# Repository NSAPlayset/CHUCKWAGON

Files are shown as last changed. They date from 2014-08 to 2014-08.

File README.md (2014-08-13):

#CHUCKWAGON Firmware

This is the demo code used during our [DEF CON 22 talk](https://www.defcon.org/html/defcon-22/dc-22-speakers.html#Datko). The full slides are [here](https://cryptotronix.files.wordpress.com/2014/08/dc_22_diy_hardware_implant.pdf).

The Arduino sketch can be uploaded to the ATmega32p on the [CryptoCape](https://www.sparkfun.com/products/12773) and the bash scripts are used by the target and host.

## Hardware Files

In the Hardware folder, you'll find the schematic, EAGLE CAD files, and BOM for the CHUCKWAGON. You can get the board directly from [OSH Park](https://oshpark.com/shared_projects/FfikIrhc).

### Connecting the CHUCKWAGON

Attach the male VGA adapter to your target. The LED will indicate if power is being supplied from your target. If so, then you can probably receive up to 1A for your implant. If you are using a 5V Logic system, use the SDA and SCL pins directly. If you are using a 3.3V system, use the 3.3V versions. If you do this, you must supply 3.3V to the 3.3V pin.

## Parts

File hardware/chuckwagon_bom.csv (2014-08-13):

Digi-Key Part Number | Manufacturer | Manufacturer Part Number | Customer Reference | Quantity 1 | Quantity 2 | Quantity 3 | Mfg Std Lead Time | Description | Comments | RoHS Status | Lead Free Status | REACH Status
609-4022-ND | FCI | 10090926-P154XLF |  | 1 | 0 | 0 | 12 Weeks | DSUB HD MALE R/A 15POS SOLDR T/H |  | RoHS Compliant | Lead free | Unaffected Jun-2011
BSS138CT-ND | FAIRCHILD SEMICONDUCTOR (VA) | BSS138 |  | 2 | 0 | 0 | 7 Weeks | MOSFET N-CH 50V 220MA SOT-23 | Alternate Packaging Exists | RoHS Compliant | Lead free | Unaffected Jun-2011
SI2323DDS-T1-GE3CT-ND | VISHAY SILICONIX (VA) | SI2323DDS-T1-GE3 |  | 1 | 0 | 0 | 14 Weeks | MOSFET P-CH 20V 5.3A SOT-23 | Alternate Packaging Exists | RoHS Compliant | Lead free | Not Available
541-1784-1-ND | VISHAY DALE (VA) | RCG060310K0FKEA |  | 4 | 0 | 0 | 10 Weeks | RES 10K OHM 1/10W 1% 0603 SMD | Alternate Packaging Exists | RoHS Compliant | Lead free | Not Available
541-1799-1-ND | VISHAY DALE (VA) | RCG06031K00JNEA |  | 1 | 0 | 0 | 10 Weeks | RES 1K OHM 1/10W 5% 0603 SMD | Alternate Packaging Exists | RoHS Compliant | Lead free | Not Available
160-1436-1-ND | LITE-ON INC (VA) | LTST-C190KRKT |  | 1 | 0 | 0 | 8-10 Weeks | LED SUPER RED CLEAR 0603 SMD | Alternate Packaging Exists | RoHS Compliant | Lead free | Not Available

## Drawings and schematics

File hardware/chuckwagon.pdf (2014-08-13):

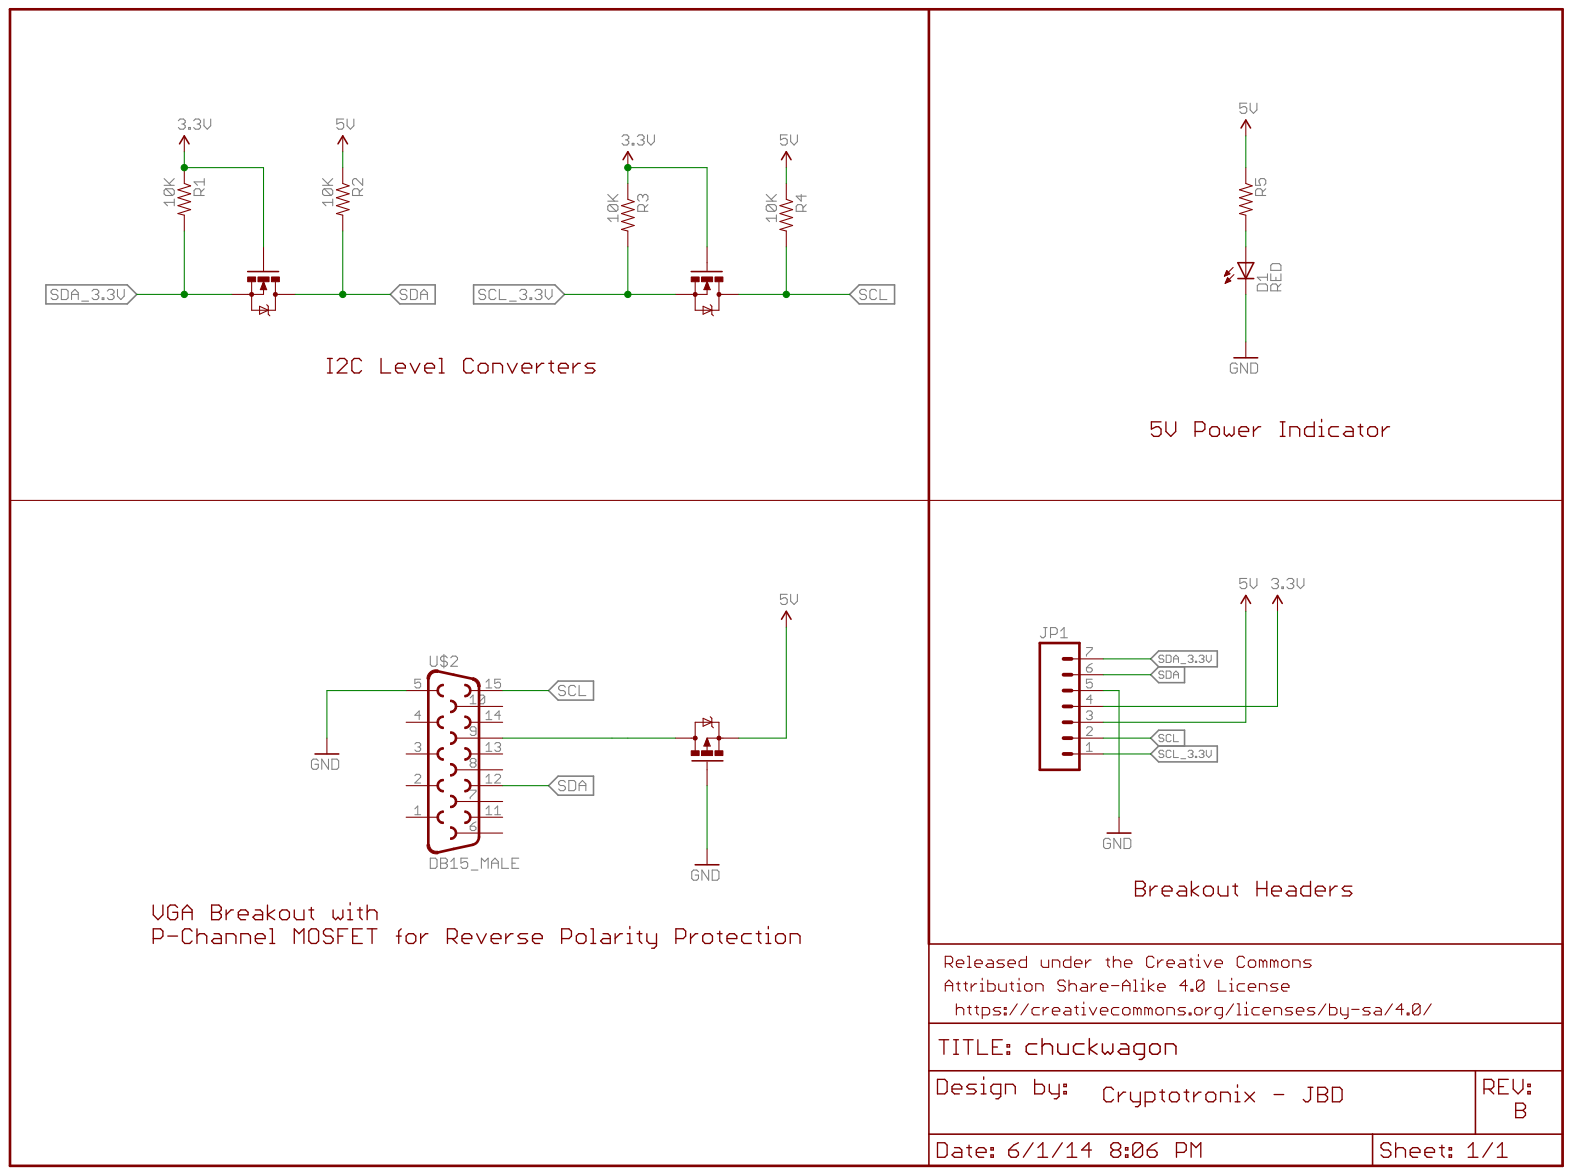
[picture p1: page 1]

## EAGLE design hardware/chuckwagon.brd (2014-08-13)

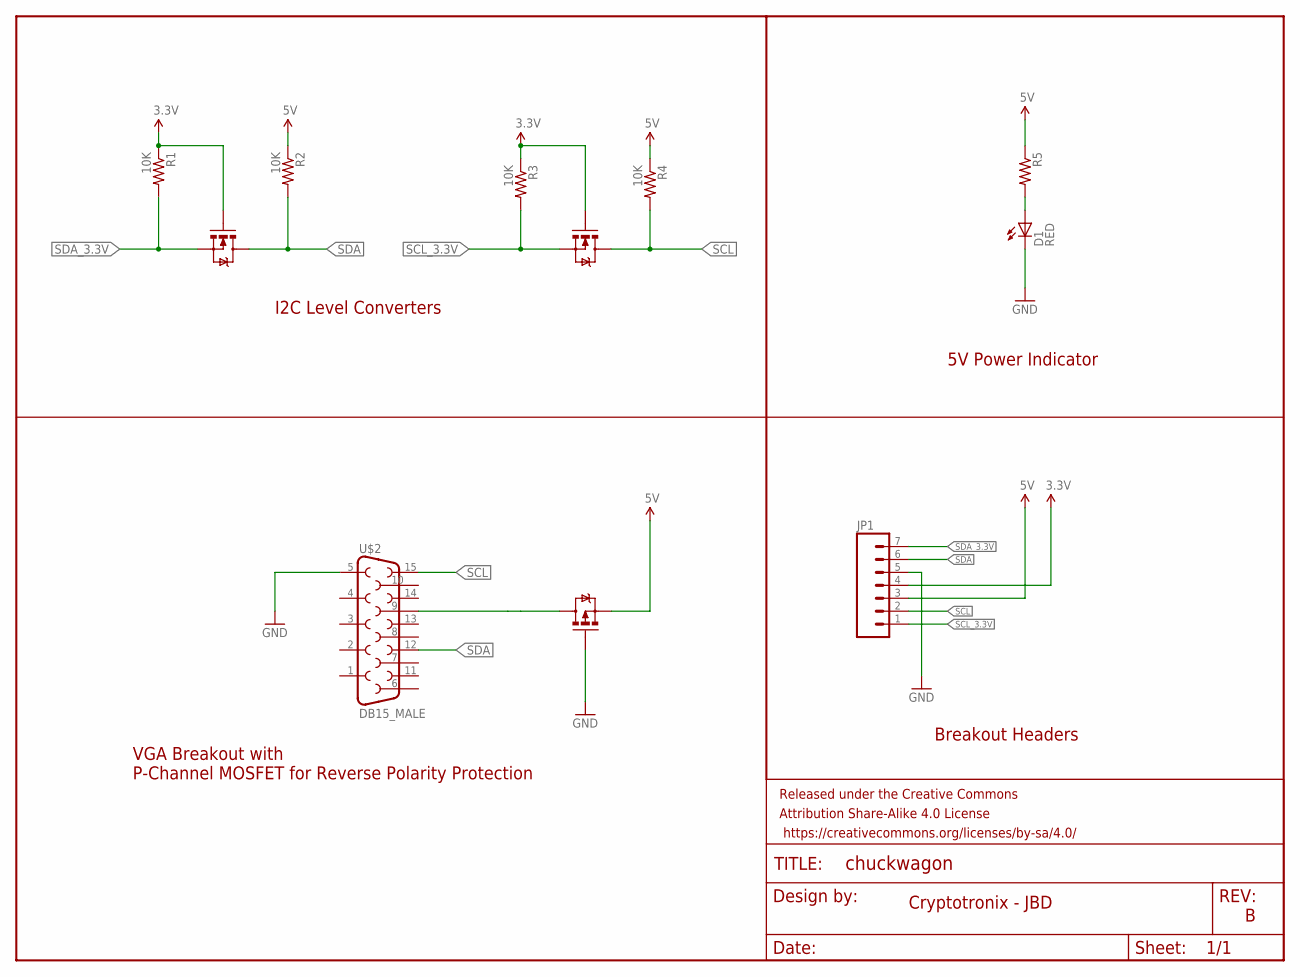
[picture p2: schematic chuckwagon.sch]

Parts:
D1: RED; LED-0603
FRAME1: FRAME-LETTER; CREATIVE_COMMONS
JP1: M07; 1X07
Q1, Q2: MOSFET-NCHANNELBSS123LT1G; SOT23
Q3: MOSFET-PCHANNEL; SOT23-3
R1, R2, R3, R4: 10K; 0603-RES
R5: RESISTOR0603-RES; 0603-RES
U$2: DB15_MALE

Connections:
3.3V: JP1.4, Q1.1 (G), Q2.1 (G), R1.1, R3.1
5V: JP1.3, Q3.2 (S), R2.1, R4.1, R5.1
GND: D1.C, JP1.5, Q3.1 (G), U$2.5
unnamed: D1.A, R5.2
unnamed: Q3.3 (D), U$2.9
SCL: JP1.2, Q2.3 (D), R4.2, U$2.15
SCL_3.3V: JP1.1, Q2.2 (S), R3.2
SDA: JP1.6, Q1.3 (D), R2.2, U$2.12
SDA_3.3V: JP1.7, Q1.2 (S), R1.2

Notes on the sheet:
I2C Level Converters
Breakout Headers
VGA Breakout with P-Channel MOSFET for Reverse Polarity Protection
5V Power Indicator
Cryptotronix - JBD

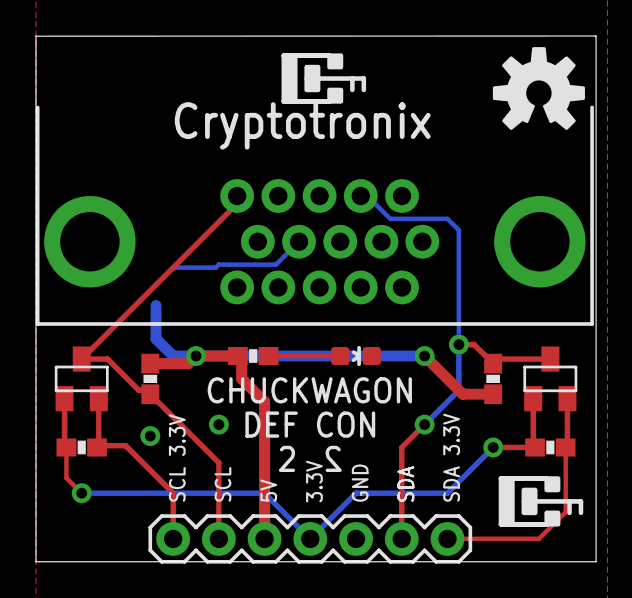
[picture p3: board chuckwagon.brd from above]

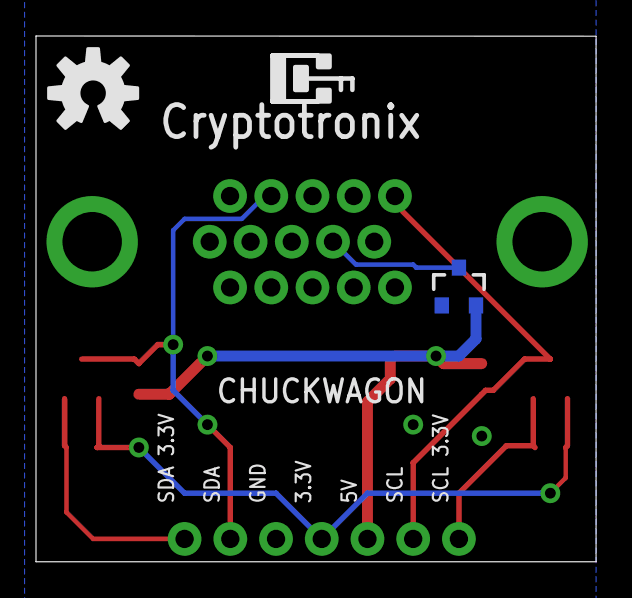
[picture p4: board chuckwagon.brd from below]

Board: 2 copper layers, 31.1 x 29.2 mm, 14 parts (2 on the bottom side), 9 nets.

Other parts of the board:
U$1, U$3: OSHW-LOGO-M

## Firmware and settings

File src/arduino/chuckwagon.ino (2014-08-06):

#include <Wire.h>

#define MAX_MSG_SIZE 32

char msg[MAX_MSG_SIZE];
int done_copy_pin = 2;
int msg_ready_pin = 3;

volatile bool done_copy = true;

void setup()
{
  Wire.begin(0x42);
  Wire.onReceive(receive_i2c);
  Wire.onRequest(request_i2c);

  Serial.begin(9600);

  /* Setup the GPIO to the BBB to indicate when a msg is ready */
  pinMode (msg_ready_pin, OUTPUT);
  clear_bbb_signal ();
}

void loop()
{
  delay(100);
}

void signal_bbb ()
{
  digitalWrite (msg_ready_pin, HIGH);
}

void clear_bbb_signal ()
{
  digitalWrite (msg_ready_pin, LOW);
}

void receive_i2c(int num_bytes)
{


  memset (msg, sizeof(msg), 0);

  Serial.println("Num bytes");
  Serial.print(num_bytes);
  Serial.println("");

  Serial.println("Receiving msg:");
  for (int x = 0; x < MAX_MSG_SIZE && x < num_bytes; x++)
    {
      msg[x] = (char) Wire.read();
      Serial.print(msg[x]);
    }

  done_copy = false;

  Serial.print("\n");

  signal_bbb ();


}

void request_i2c ()
{
  Serial.print ("Received request");
  Wire.write (msg);
  done_copy = true;
  clear_bbb_signal ();
}

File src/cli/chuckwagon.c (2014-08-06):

#include <errno.h>
#include <string.h>
#include <stdio.h>
#include <stdlib.h>
#include <signal.h>
#include <unistd.h>
#include <linux/i2c-dev.h>
#include <sys/ioctl.h>
#include <sys/types.h>
#include <sys/stat.h>
#include <fcntl.h>
#include <assert.h>
#include <argp.h>

const char *argp_program_version = "chuckwagon 0.1";
const char *argp_program_bug_address = "support@cryptotronix.com";

static char doc[] =
  "Chuckwagon utility\n";

static char args_doc[] = "DIRECTION";
#define NUM_ARGS 1

struct arguments
{
  char *args[NUM_ARGS];
};

static error_t
parse_opt (int key, char *arg, struct argp_state *state)
{
  /* Get the input argument from argp_parse, which we
     know is a pointer to our arguments structure. */
  struct arguments *arguments = state->input;
     
  switch (key)
    {
    case ARGP_KEY_ARG:

      if (state->arg_num >= NUM_ARGS)
	{
	  /* Too many arguments. */
	  argp_usage (state);
	}
     
      arguments->args[state->arg_num] = arg;
      
      break;
     
    case ARGP_KEY_END:

      if (state->arg_num < NUM_ARGS)
	{
	  /* Not enough arguments. */
	  argp_usage (state);
	}

      break;
     
    default:
      return ARGP_ERR_UNKNOWN;
    }
  return 0;
}


static struct argp argp = {0, parse_opt, args_doc, doc};

int
main(int argc, char **argv){

  struct arguments arguments;

  argp_parse (&argp, argc, argv, 0, 0, &arguments);

  if (*arguments.args[0] == 'r' || *arguments.args[0] == 'w')
    {
      // Arguments match
    }
  else
    {
      printf ("Must specify r or w, see help\n");
      exit (1);
    }
  
  char *bus = "/dev/i2c-1"; 
  int addr = 0x42;          
  char buf[32] = {0};
  int fd = 0;
  int result = 0;

  if ((fd = open(bus, O_RDWR)) < 0) {
    /* ERROR HANDLING: you can check errno to see what went wrong */
    perror("Failed to open the i2c bus");
    exit(1);
  }


 if (ioctl(fd, I2C_SLAVE, addr) < 0) {
   perror("Failed to acquire bus access and/or talk to slave.\n");
   /* ERROR HANDLING; you can check errno to see what went wrong */
   exit(1);
 }

 if (*arguments.args[0] == 'w')
   {
     int num_read = 0;
     num_read = read (0, buf, sizeof(buf));

     if (num_read > 0);
     {
       result = write (fd, buf, num_read);
     }
   }
 else
   {
     int num_read = 0;
     num_read = read (fd, buf, sizeof(buf));

     int end_of_string = 0;
     int x = 0;

     /* Truncate the string to the first newline */
     for (x = 0; x < num_read; x++)
       {
	 if (buf[x] == '\n' && 0 == end_of_string)
	   {
	     end_of_string = (x == num_read) ? num_read : x + 1;
	   }
       }

     if (num_read > 0)
       {
	 result = write (1, buf, end_of_string);
       }

   }
 
 close (fd);

 result = (result > 0) ? 0 : result;

 return result;

}

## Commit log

2014-07-24 Adds landing page.
2014-08-06 Adds initial arduino sketch.
2014-08-13 Adds hardware files
    [chuckwagon.brd, chuckwagon.sch, chuckwagon_bom.csv]
2014-08-13 adds schematic

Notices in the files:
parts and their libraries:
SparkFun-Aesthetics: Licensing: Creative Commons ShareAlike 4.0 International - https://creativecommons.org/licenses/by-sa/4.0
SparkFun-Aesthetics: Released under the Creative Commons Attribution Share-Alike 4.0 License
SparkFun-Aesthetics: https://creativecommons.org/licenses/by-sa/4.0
